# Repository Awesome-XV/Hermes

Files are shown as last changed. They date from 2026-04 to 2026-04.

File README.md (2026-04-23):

# Hermes
This is a project that detects motion/object presence. It  uses a TOF distance sensor to detect an object moving or in general. Once the sensor detects it, it sends the signal to the LED to flash. There is also a button that allows for the ability to change units and modes. This makes it work like a motion sensor too, batteries have been included for better mobility and placement of this device.

# Why
I made this project so I can do more complex things in Kicad and have a better understanding on how to use footprints and symbols. This is the first time that I had to go and find them completely on my own. I also added SMD components that will make it cooler. I also added an OLED screen that I can integrate functionality into. Overall, its just a complexity upgrade from my last project so that I can get more into hardware

# Some Pics






# BOM Table
| Name | Purpose | Quantity | Total Cost (USD) | Distributor | Link |
|---|---|:---:|---:|---|---|
| PCB | Where everything is on top of | 1 | $2.00 | JLCPCB | N/A |
| VL53L1CXV0FY/1 | Proximity Sensor | 1 | $5.77 | Digikey | [Buy](https://www.digikey.com/en/products/detail/stmicroelectronics/VL53L1CXV0FY-1/8258055) |
| CONN HEADER VERT 1POS 2.54MM | Connection from battery pack | 10 | $0.29 | Digikey | [Buy](https://www.digikey.com/en/products/detail/adam-tech/PH1-01-UA/9830231) |
| RES 110 OHM 5% 1/8W AXIAL | Resistor | 10 | $0.22 | Digikey | [Buy](https://www.digikey.com/en/products/detail/stackpole-electronics-inc/CF18JT110R/1741570) |
| DIODE SCHOTTKY 20V 1A DO41 | Prevent reverse flow into batteries | 1 | $0.18 | Digikey | [Buy](https://www.digikey.com/en/products/detail/smc-diode-solutions/1N5817/21705460) |
| XIAO RP2040 | MC | 1 | $4.68 | Digikey | [Buy](https://www.digikey.com/en/products/detail/seeed-technology-co-ltd/102010428/14672129) |
| RES 4.7K OHM 5% 1/8W AXIAL | Resistor | 10 | $0.20 | Digikey | [Buy](https://www.digikey.com/en/products/detail/stackpole-electronics-inc/CF18JT4K70/1741708) |
| CONN HDR 4POS 0.1 GOLD PCB | 4 Pin connector | 1 | $0.38 | Digikey | [Buy](https://www.digikey.com/en/products/detail/sullins-connector-solutions/PPPC041LFBN-RC/810176) |
| CAP CER 0.1UF 50V Z5U RADIAL | Capacitator | 2 | $0.72 | Digikey | [Buy](https://www.digikey.com/en/products/detail/kemet/C315C104M5U5TA/817927) |
| RES 10K OHM 5% 1/4W AXIAL | Resistor | 10 | $0.20 | Digikey | [Buy](https://www.digikey.com/en/products/detail/stackpole-electronics-inc/CF14JT10K0/1741265) |
| BATT HOLDER AA 3 CELL 6" LEADS | Hold Batteries | 1 | $1.76 | Digikey | [Buy](https://www.digikey.com/en/products/detail/keystone-electronics/2465/303814) |
| LED RED DIFFUSED 5MM ROUND T/H | For light | 1 | $0.16 | Digikey | [Buy](https://www.digikey.com/en/products/detail/w%C3%BCrth-elektronik/151051RS11000/4490012) |
| Solder Flux | For my Non-THT components | 1 | $5.99 | Amazon | [Buy](https://www.amazon.com/Solder-Liquid-Soldering-Electrical-Electronics/dp/B0FF793RRY/) |
| PCB Holder | To hold my THT components | 1 | $8.99 | Harbor Freight | N/A |
| D6R90 F2 LFS | Button | 1 | $1.56 | Digikey | [Buy](https://www.digikey.com/en/products/detail/c-k/D6R90-F2-LFS/1466352) |
| Shipping | Move these parts | 1 | $3.12 | JLCPCB, Digikey | N/A |
| Tax | I have to pay | 1 | $4.47 | Digikey | N/A |
| **Total** | | | *$40.69* | | |

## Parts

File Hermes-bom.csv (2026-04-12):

Name | Purpose | Quantity | Total Cost (USD) | Link | Distributor
Solder Flux | For my Non-THT components | 1 | 5.99 | https://www.amazon.com/Solder-Liquid-Soldering-Electrical-Electronics/dp/B0FF793RRY?rnid=1243644011 | Amazon
PCB Holder | To hold my THT components | 1 | 8.99 |  | Harbor Freight
D6R90 F2 LFS | Button | 1 | 1.56 | https://www.digikey.com/en/products/detail/c-k/D6R90-F2-LFS/1466352 | Digikey
PCB | Where everything is on top of | 1 | 2.00 |  | JLCPCB
VL53L1CXV0FY/1 | Proximity Sensor | 1 | 5.77 | https://www.digikey.com/en/products/detail/stmicroelectronics/VL53L1CXV0FY-1/8258055 | Digikey
XIAO RP2040 | MC | 1 | 4.68 | https://www.digikey.com/en/products/detail/seeed-technology-co-ltd/102010428/14672129 | Digikey
RES 4.7K OHM 5% 1/8W AXIAL | Resistor | 10 | 0.20 | https://www.digikey.com/en/products/detail/stackpole-electronics-inc/CF18JT4K70/1741708 | Digikey
CONN HDR 4POS 0.1 GOLD PCB | 4 Pin connector | 1 | 0.38 | https://www.digikey.com/en/products/detail/sullins-connector-solutions/PPPC041LFBN-RC/810176 | Digikey
CAP CER 0.1UF 50V Z5U RADIAL | Capacitator | 2 | 0.72 | https://www.digikey.com/en/products/detail/kemet/C315C104M5U5TA/817927 | Digikey
RES 10K OHM 5% 1/4W AXIAL | Resistor | 10 | 0.20 | https://www.digikey.com/en/products/detail/stackpole-electronics-inc/CF14JT10K0/1741265 | Digikey
BATT HOLDER AA 3 CELL 6" LEADS | Hold Batteries | 1 | 1.76 | https://www.digikey.com/en/products/detail/keystone-electronics/2465/303814 | Digikey
DIODE SCHOTTKY 20V 1A DO41 | Prevent reverse flow into batteries | 1 | 0.18 | https://www.digikey.com/en/products/detail/smc-diode-solutions/1N5817/21705460 | Digikey
RES 110 OHM 5% 1/8W AXIAL | Resistor | 10 | 0.22 | https://www.digikey.com/en/products/detail/stackpole-electronics-inc/CF18JT110R/1741570 | Digikey
CONN HEADER VERT 1POS 2.54MM | Connection from battery pack | 10 | 0.29 | https://www.digikey.com/en/products/detail/adam-tech/PH1-01-UA/9830231 | Digikey
LED RED DIFFUSED 5MM ROUND T/H | For light | 1 | 0.16 | https://www.digikey.com/en/products/detail/w%C3%BCrth-elektronik/151051RS11000/4490012 | Digikey

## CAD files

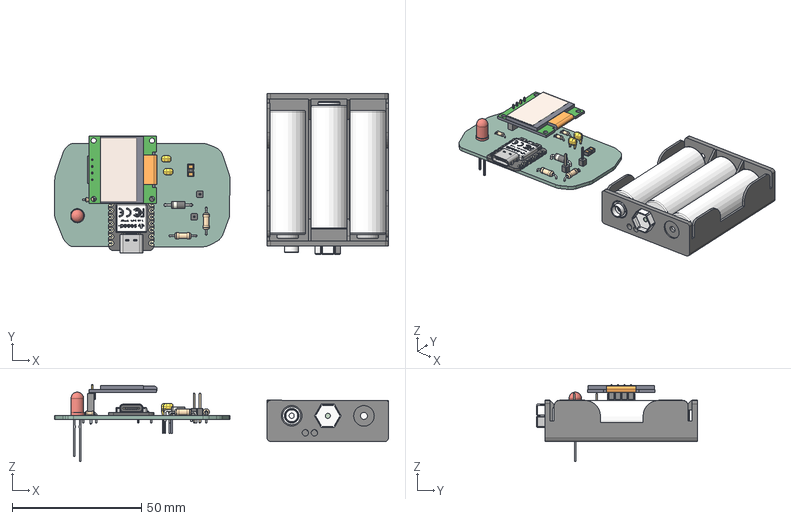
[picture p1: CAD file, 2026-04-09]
Hermes.step
129.4 x 62.2 x 30.0 mm

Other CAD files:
Hermes.f3z

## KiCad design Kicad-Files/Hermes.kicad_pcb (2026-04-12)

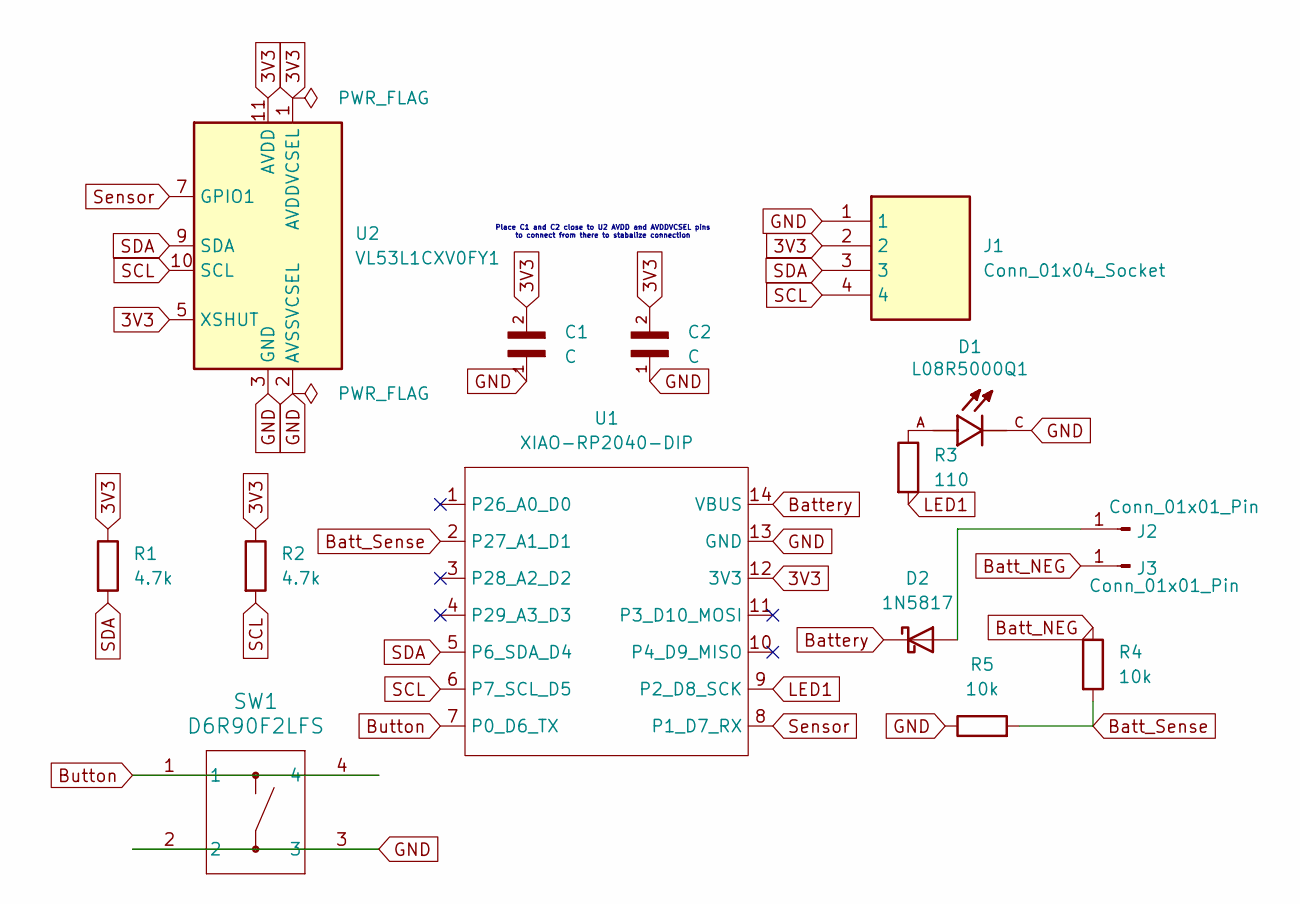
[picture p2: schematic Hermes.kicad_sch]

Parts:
C1, C2: C; CAPRR254W54L381T254H466; PARTREV 12/14/2020
D1: L08R5000Q1; LEDRD254W57D500H1070; PARTREV NA
D2: 1N5817; D_DO-41_SOD81_P10.16mm_Horizontal
J1: Conn_01x04_Socket; RHDR4W80P0X254_1X4_1066X254X850P; Manufacturer_Part_Number PPPC041LFBN-RC
J2, J3: Conn_01x01_Pin; PinHeader_1x01_P2.54mm_Vertical
R1, R2: 4.7k; R_Axial_DIN0204_L3.6mm_D1.6mm_P5.08mm_Horizontal
R3: 110; R_Axial_DIN0204_L3.6mm_D1.6mm_P5.08mm_Horizontal
R4, R5: 10k; R_Axial_DIN0207_L6.3mm_D2.5mm_P10.16mm_Horizontal
SW1: D6R90F2LFS; D6R90_CNK
U1: XIAO-RP2040-DIP
U2: VL53L1CXV0FY1; ST_VL53L1x

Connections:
3V3: C1.2, C2.2, J1.2, R1.1, R2.1, U1.12 (3V3), U2.1 (AVDDVCSEL), U2.5 (XSHUT), U2.11 (AVDD)
Batt_NEG: J3.1, R4.1
Batt_Sense: R4.2, R5.2, U1.2 (P27_A1_D1)
Battery: D2.1 (K), U1.14 (VBUS)
Button: SW1.1, SW1.4, U1.7 (P0_D6_TX)
GND: C1.1, C2.1, D1.C, J1.1, R5.1, SW1.2, SW1.3, U1.13 (GND), U2.2 (AVSSVCSEL), U2.3 (GND), U2.4 (GND), U2.6 (GND), U2.12 (GND)
LED1: R3.2, U1.9 (P2_D8_SCK)
unnamed: D1.A, R3.1
unnamed: D2.2 (A), J2.1
SCL: J1.4, R2.2, U1.6 (P7_SCL_D5), U2.10 (SCL)
SDA: J1.3, R1.2, U1.5 (P6_SDA_D4), U2.9 (SDA)
Sensor: U1.8 (P1_D7_RX), U2.7 (GPIO1)

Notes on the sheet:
Place C1 and C2 close to U2 AVDD and AVDDVCSEL pins to connect from there to stabalize connection

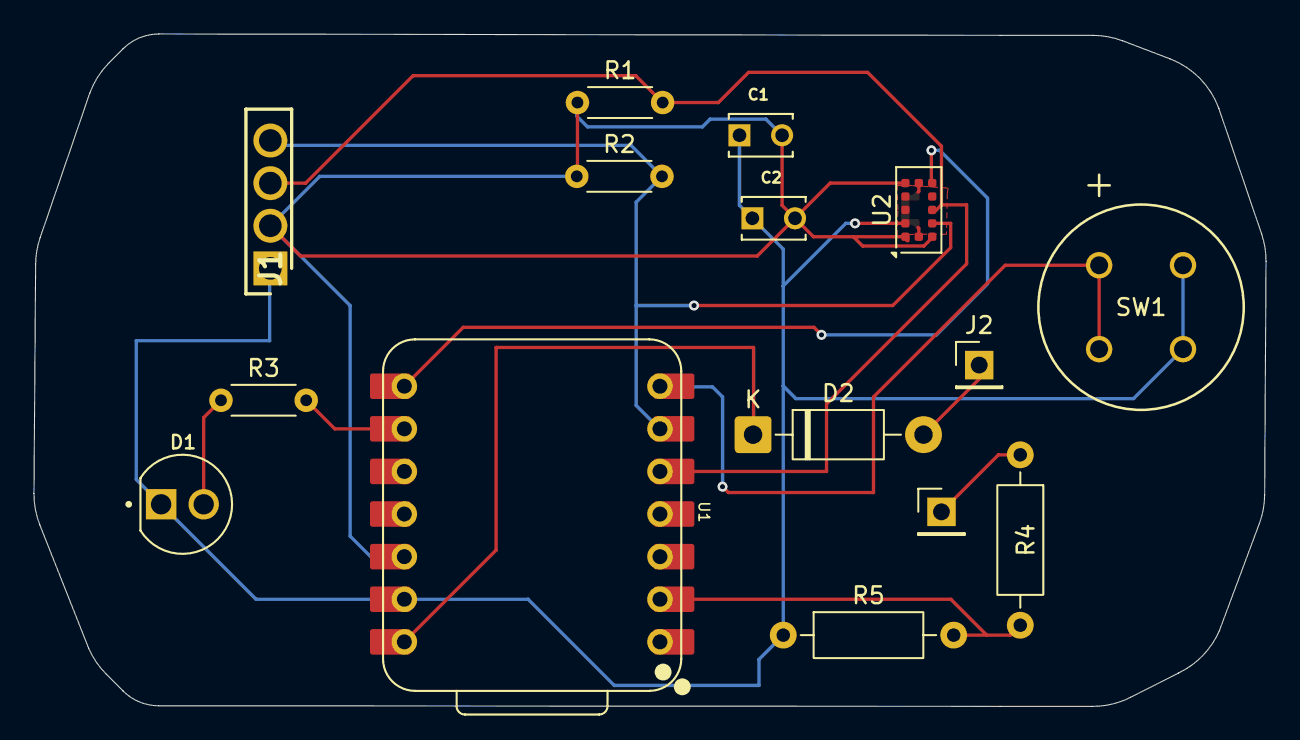
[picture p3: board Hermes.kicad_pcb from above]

Board: 2 copper layers, 73.4 x 40.1 mm, 15 parts (0 on the bottom side), 12 nets.

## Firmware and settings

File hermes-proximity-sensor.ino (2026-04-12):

#include <Wire.h>
#include <Adafruit_VL53L1X.h>
#include <Adafruit_GFX.h>
#include <Adafruit_SSD1306.h>

#define INTERRUPT_PIN 7
#define LED_PIN 8
#define BATTERY_PIN A1
#define BUTTON_PIN 6
#define SCREEN_WIDTH 128
#define SCREEN_HEIGHT 64

Adafruit_SSD1306 oled(SCREEN_WIDTH, SCREEN_HEIGHT , &Wire, -1);
Adafruit_VL53L1X sensor(-1, INTERRUPT_PIN);

bool useImperial  = false;

float getBatteryVoltage() {
  return((analogRead(BATTERY_PIN) / 4095.0) * 3.3) * 2.0;
}

int batteryPercent() {
  int percent = (int)(((getBatteryVoltage() - 2.7) / 1.8) * 100);
  return percent < 0 ? 0 : percent > 100 ? 100 : percent;
}

void batteryIcon(int x, int y, int percent) {
  oled.drawRect(x, y, 20, 10, WHITE);
  oled.fillRect(x+20, y+3, 2, 4, WHITE);
  oled.fillRect(x+1, y+1, (int)(18.0*percent / 100), 8, WHITE);
}

void oledError(const char* msg) {
  oled.clearDisplay();
  oled.setCursor(0, 24);
  oled.print(msg);
  while(1) {
    digitalWrite(LED_PIN, !digitalRead(LED_PIN));
    delay(400);
  }
}

void setup() {
  Serial.begin(115200);
  pinMode(LED_PIN, OUTPUT);
  analogReadResolution(12);
  Wire.begin();

  if(!oled.begin(SSD1306_SWITCHCAPVCC, 0x3C)) {
    oledError("Display failed to start");
  }

  oled.clearDisplay();
  oled.setTextColor(WHITE);
  oled.setCursor(30, 28);
  oled.print("Hermes");
  oled.display();
  delay(1200);

  if(!sensor.begin(0x29, &Wire)) {
    oledError("Sensor failed to start");
  }

  sensor.startRanging();
}

void loop() {
  if(digitalRead(BUTTON_PIN) == LOW) {
    useImperial = useImperial;
    delay(500);
  }

  int16_t distance = -1;
  bool reading = false;

  if(sensor.dataReady()) {
    distance = sensor.distance();
    sensor.clearInterrupt();
    reading = distance > 0;
  }

  digitalWrite(LED_PIN, reading && distance < 500);
  int percent = batteryPercent();
  float voltage = getBatteryVoltage();

  oled.clearDisplay();
  oled.setTextSize(1);
  oled.setCursor(0, 0);
  oled.print("Hermes");

  batteryIcon(95, 0, percent);
  oled.setCursor(100, 12);
  oled.print(percent);
  oled.print("%");

  oled.drawLine(0, 16, 127, 16, WHITE);
  oled.setTextSize(2);
  oled.setCursor(0, 24);

  if(reading) {
    if(useImperial) {
      float inches = distance / 25.4;
      if(inches >= 12.0) {
        int feet = (int)(inches / 12);
        float remainingInches = inches - (feet * 12);
        oled.print(feet);
        oled.setTextSize(1);
        oled.print("ft ");
        oled.setTextSize(2);
        oled.print(remainingInches, 1);
        oled.setTextSize(1);
        oled.print("in");
      } else {
        oled.print(inches, 1);
        oled.setTextSize(1);
        oled.print(" in");
      }
    } else {
      if(distance >= 1000) {
        oled.print(distance / 10);
        oled.setTextSize(1);
        oled.print(" cm");
      } else {
        oled.print(distance);
        oled.setTextSize(1);
        oled.print(" mm");
      }
    }
  } else {
    oled.print("---");
  }
  if(percent < 20) {
    oled.setTextSize(1);
    oled.setCursor(0, 54);
    oled.print("Low Battery (");
    oled.print(voltage, 1);
    oled.print("v)");
  }

  oled.display();
  delay(100);
}

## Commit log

2026-04-09 Add PCB and STEP files
    [Hermes.kicad_pcb, Hermes.kicad_sch, Hermes.step]
2026-04-09 Organize files and add prod zip file
    [Hermes.kicad_pcb, Hermes.kicad_sch]
2026-04-10 Add BOM and update README
    [Hermes-bom.csv]
2026-04-12 Fix BOM update files and add a button to the pcb
    [Hermes-bom.csv, Hermes.kicad_pcb, Hermes.kicad_sch]
2026-04-23 Add CAD source files
    [Hermes.f3z]
2026-04-23 Change CAD
    [Hermes.f3z]
